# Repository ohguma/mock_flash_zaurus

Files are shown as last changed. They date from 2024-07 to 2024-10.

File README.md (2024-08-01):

# フラッシュザウルスもどき

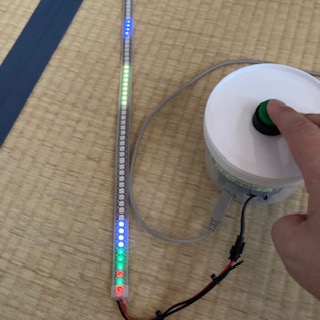
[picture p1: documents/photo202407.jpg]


- Arduino UnoとLEDテープ、パッシブブザーを用いた、フラッシュザウルス風ゲーム。
- 「フラッシュザウルス」については「[東京フレンドパークのアトラクション一覧](https://ja.wikipedia.org/wiki/%E6%9D%B1%E4%BA%AC%E3%83%95%E3%83%AC%E3%83%B3%E3%83%89%E3%83%91%E3%83%BC%E3%82%AF%E3%81%AE%E3%82%A2%E3%83%88%E3%83%A9%E3%82%AF%E3%82%B7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)」を参考に。

## ゲーム概要

以下は、本物のフラッシュザウルスのルールでなく、本スケッチでのルール。
+ ボタンを押すとゲーム開始。
+ 1ゲーム10ラウンド制。
+ arduino本体から離れた位置からLEDドットが近づいてくるので黄色LED上でボタンを押す。
+ 黄色LED上でボタンを押すことができればそのラウンドは成功。黄色LEDを外れると失敗。
+ arduino寄りの10LEDでポイントを表示する。成功は緑、失敗は赤。
+ ラウンド開始後、LEDドットはランダムウエイト後にランダム位置からランダム速度で近づく。
+ 初回の失敗か続けて失敗すると、落下速度の基準を落とす。
+ 黄色LEDはラウンドが進むと短くなる。また配置はランダムにずれる。
+ ボタンを押しながらarduino本体の電源を入れると輝度調整モードに入る。希望輝度でボタンを離す。

## 参考

- https://github.com/adafruit/Adafruit_NeoPixel
  - ライブラリマネージャからインストールしておく。
- https://github.com/lalaso2000/Music/
  - 本ソースに含む。曲データは適宜差し替えた。

## 利用パーツ

リンク先は作例で使用したもの。

+ Arduino UNO Rev.3 で動作確認
  - due は IO電圧が3.3Vだが、WS2812B の操作は可能、ただし、tone()が利用できないため、本スケッチはそのまま利用できない。
    - due 用 tone() の例：https://forum.arduino.cc/t/arduino-due-and-tone/133302/2
  - その他の arduino でも基本的には動作すると思われる。
+ Arduino と LEDテープ・スイッチ・ブザー接続用のユニバーサル基板
  - [スイッチ・サイエンス：Arduino用バニラシールド基板](https://www.switch-science.com/products/991)
    - 別途ピンヘッダ、もしくはピンソケットが必要。
    - （説明）[スイッチ・サイエンス：バニラシールド](https://trac.switch-science.com/wiki/VanillaShield)
  - arduinoのピンソケットはシールド基板の逆接続防止に一部間隔がずれているので、一般的なユニバーサル基板を使う場合はピンヘッダを曲げてズレに対応させる（おすすめはしない）。
+ LEDテープ 144個を想定。amazonで2,000円程度。
  - arduinoのAdafruit_NeoPixelライブラリで利用できるもの。以下で動作確認した。
  - [amazon：ALITOVE WS2812B LEDテープ1m 144連 NeoPixel RGB TAPE LED 5050 SMD LEDテープライトピクセル 防水 黒いベース 5V DC](https://www.amazon.co.jp/dp/B01MYT6JH9/)
    - 2017年10月購入
  - [amazon：BTF-LIGHTING WS2812B LEDテープライト 5050 SMD RGBIC 合金ワイヤー 1m 144LEDs](https://www.amazon.co.jp/dp/B088JTMSYY/)
    - 2024年7月購入
  - WS2812B の詳細はこちらから
    - [秋月電子：マイコン内蔵RGBLED WS2812B](https://akizukidenshi.com/catalog/g/g107915/)
+ パッシブブザー
  - arduinoのtone()で利用できるもの。
  - 電源に接続するだけで音が出るものはアクティブブザーで、tone()で利用できない。
  - [amazon：KKHMF 20個パッシブブザー 電磁 ユニバーサル インピーダンス 16R 12*8.5mm ピッチ 6.5mm](https://www.amazon.co.jp/gp/product/B08LB2GYD1/)
+ 押ボタンスイッチ
  - 押している間だけONになるモーメンタリなものを使う。
  - [モノタロウ：押しボタンスイッチ AR22シリーズ 突形(Φ24) 非照光式 取付穴径22.3/25.5mm モメンタリ 1a](https://www.monotaro.com/p/3492/4644/)
    - 取付穴寸法：直径22mm。ストロークが長いと不評だった。
  - [千石通商：三和電子　OBSF-24](https://www.sengoku.co.jp/mod/sgk_cart/detail.php?code=55AU-8ALR)
    - 取付穴寸法：直径24mm。
+ ケース
  - ダイソーの食品用容器
  - ブザーは側面に穴を開け、UVレジンで固定した。

## 注意
+ LEDをあまり明るくすると電源がもたないかも。
  -  [秋月電子：マイコン内蔵RGBLED WS2812B](https://akizukidenshi.com/catalog/g/g107915/)の[データシート](https://akizukidenshi.com/goodsaffix/WS2812B_20200225.pdff)だと動作電流が「12mA」とあり、144個全てが12mA使うと「1.728A」に達する。

## 基盤情報

### 回路図

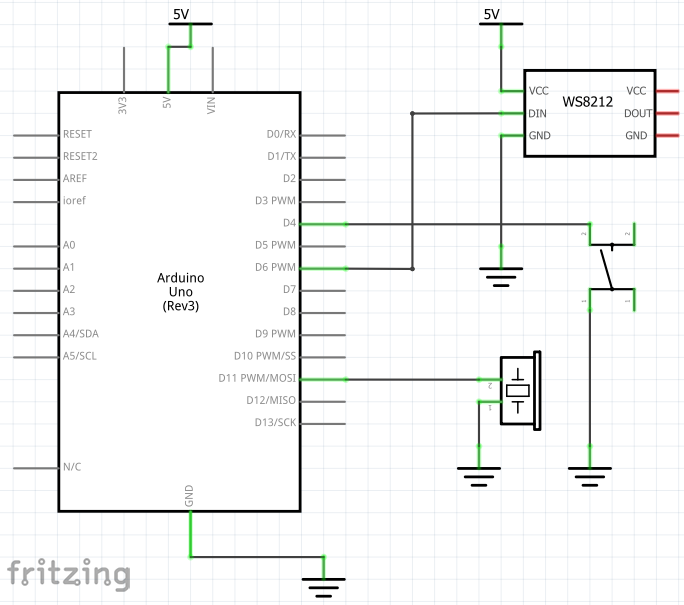
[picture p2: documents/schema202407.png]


### ブレッドボード配線例

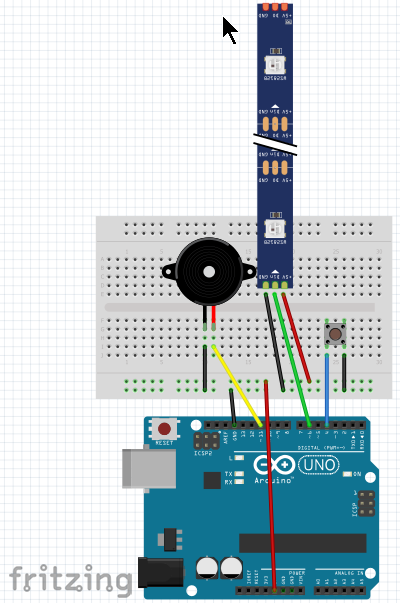
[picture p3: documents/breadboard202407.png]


### シールド基板配線例

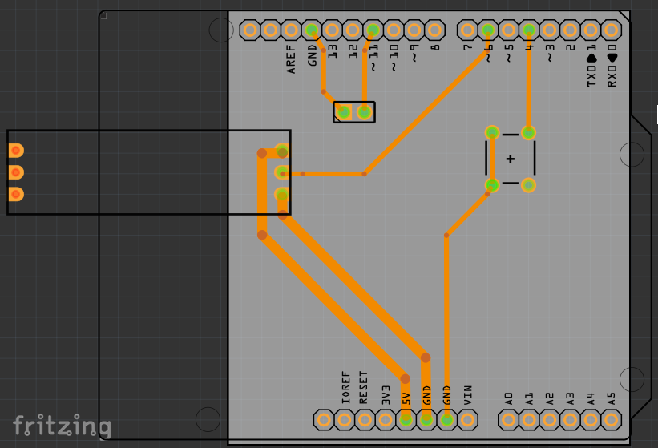
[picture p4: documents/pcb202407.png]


- ケースに入れる場合は適宜コネクタ等利用する。

## CADデータ

- 長さ1mで12mm幅のLEDテープを外径21mm、内径18mm、長さ1mのアクリルパイプにLEDテープを入れてみた。
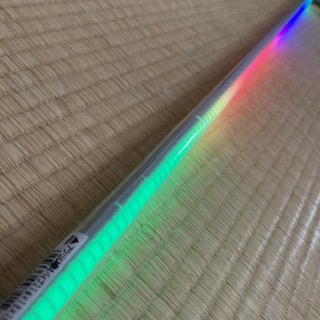
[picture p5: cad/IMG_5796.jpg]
  -  全体。
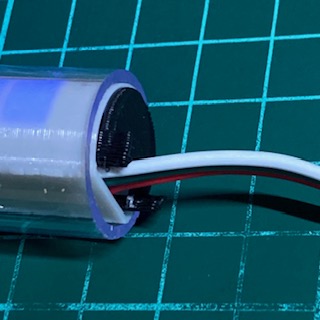
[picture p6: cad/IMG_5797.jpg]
  -  アクリルパイプの端。コードのハンダ部が折れやすいので要注意。
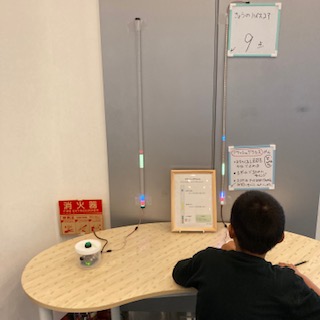
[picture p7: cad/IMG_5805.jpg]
  -   左はアクリルパイプ、右は購入時の防水用カバー。
- 3Dプリンタで作成したパーツは主に３つ
  - 光拡散カバー。長さが2種類。
    - [fz_cov11.stl](./cad/fz_cov11.stl) 長さ：75.6mm 13個
    - [fz_cov4.stl](./cad/fz_cov4.stl) 長さ：27.3mm 1個
    - 白PLA使用。光が透けるものを使う。
      - 使用フィラメント：[eSUN PLA Plus 白](https://www.amazon.co.jp/gp/product/B085TDK2KZ)
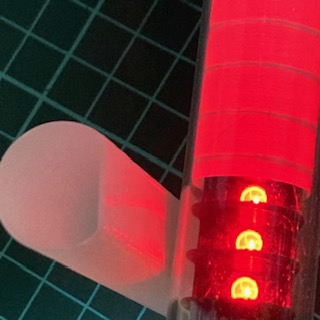
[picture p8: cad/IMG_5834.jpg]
      -  発光部の近影。カバーは筒を立てる向きに印刷。
  - 光拡散カバー内の仕切り。長さが2種類。LEDは6.9mmごとに設置されているので、仕切りも合わせる。
    - [fz_div13.stl](./cad/fz_div13.stl)  長さ：88.4mm 11個
    - [fz_div4.stl](./cad/fz_div4.stl) 長さ：27.3mm 1個
    - 黒PLA使用。光が透けないものを使う。透けると色が混ざる。
      - 使用フィラメント：[ELEGOO PLAフィラメント黒](https://www.amazon.co.jp/dp/B0BM4DQHQH)
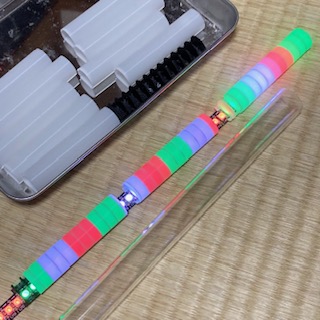
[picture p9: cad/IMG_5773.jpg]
      -  仕切り3種の比較。右上：白PLA、中：白PLAを黒マッキー塗装、左下：黒PLA。
  - アクリルパイプ両端のふた。コードの有無で2種類。 
    - [fz_futa.stl](./cad/fz_futa.stl) 
    - [fz_futa2.stl](./cad/fz_futa2.stl)
- 各STLファイルは、使用している3Dプリンタ（ANYCUBIC MEGA-S）で出力したものが、基本無加工でアクリルパイプに収まるよう大きさを調整している。
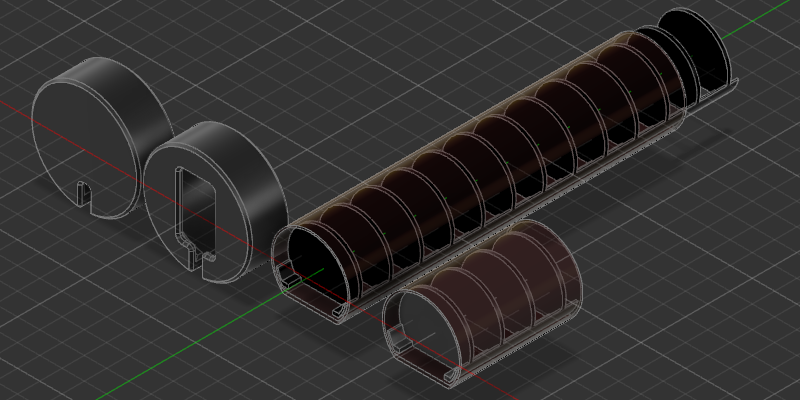
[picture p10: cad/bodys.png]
  - 
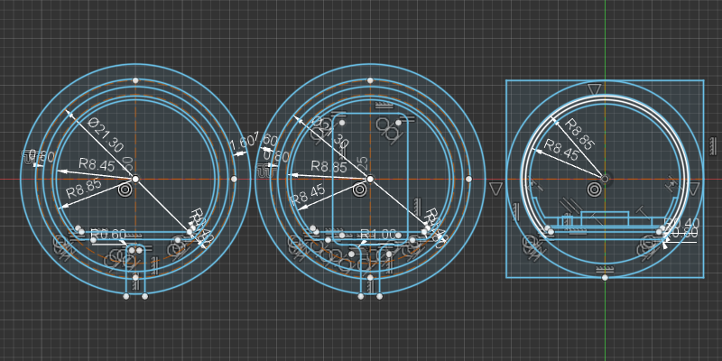
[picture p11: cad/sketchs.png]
  - 

----

- 2024-08-01 ohguma アクリルパイプへの仕込み、CADデータ追加、ソース更新
- 2024-07-18 ohguma 本ドキュメント追記、画像更新
- 2024-07-07 ohguma 低得点時の補正、ハイスコア表示、等対応
- 2024-07-06 ohguma 初版

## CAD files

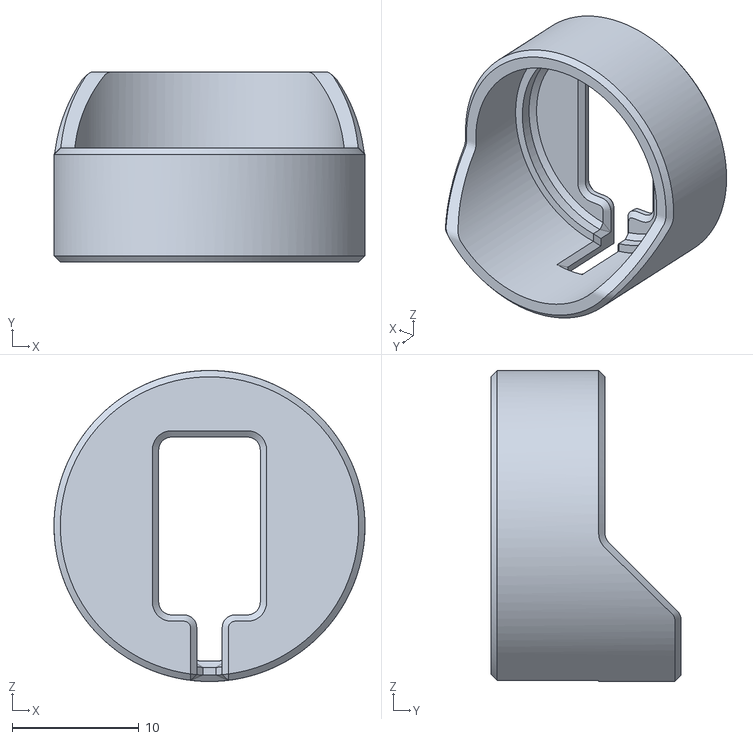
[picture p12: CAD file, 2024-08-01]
cad/fz_futa.stl
24.5 x 15.0 x 24.5

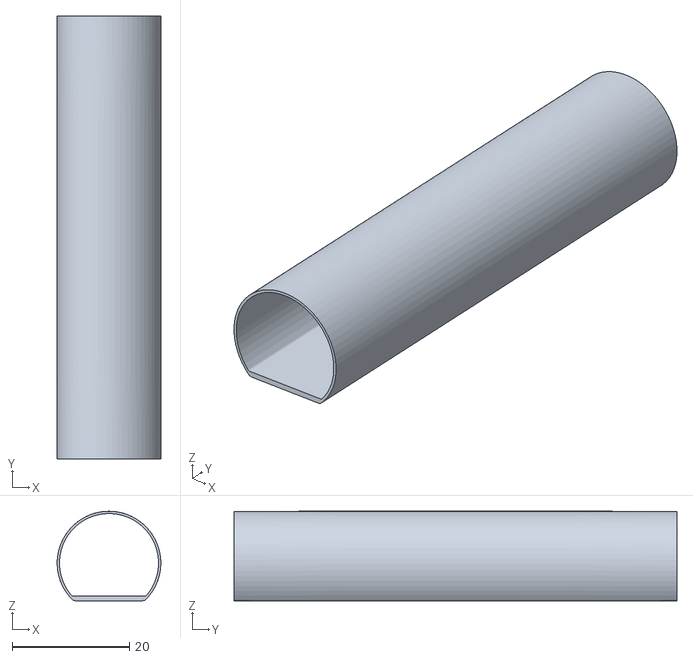
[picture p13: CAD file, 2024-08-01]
cad/fz_cov11.stl
17.7 x 75.6 x 15.3

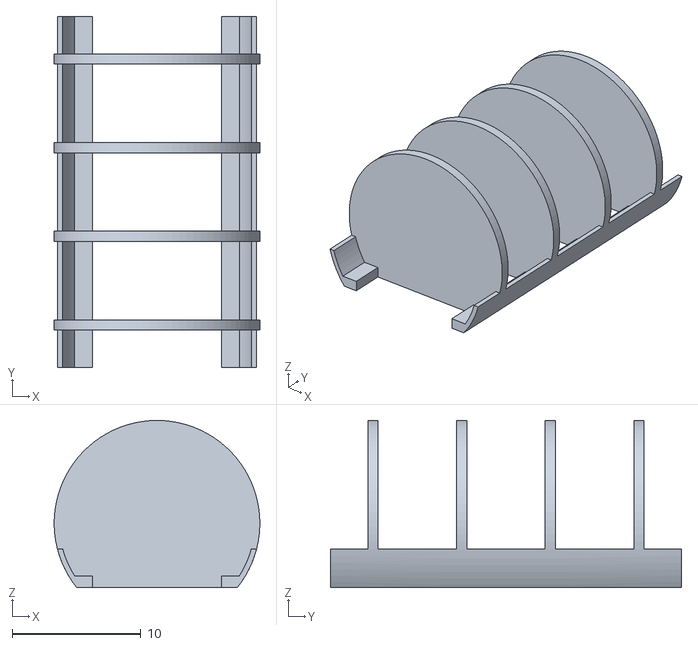
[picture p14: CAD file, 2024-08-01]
cad/fz_div4.stl
16.0 x 27.3 x 13.0

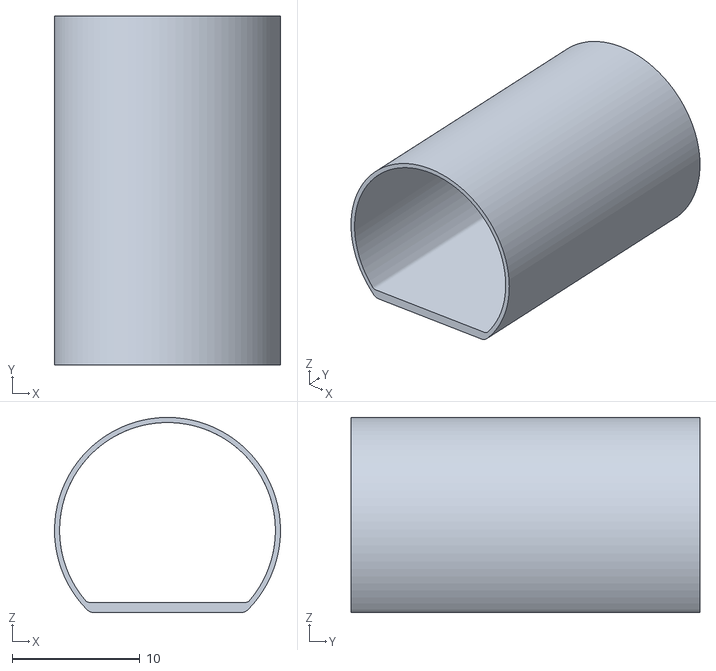
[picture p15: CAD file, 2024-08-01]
cad/fz_cov4.stl
17.7 x 27.3 x 15.3

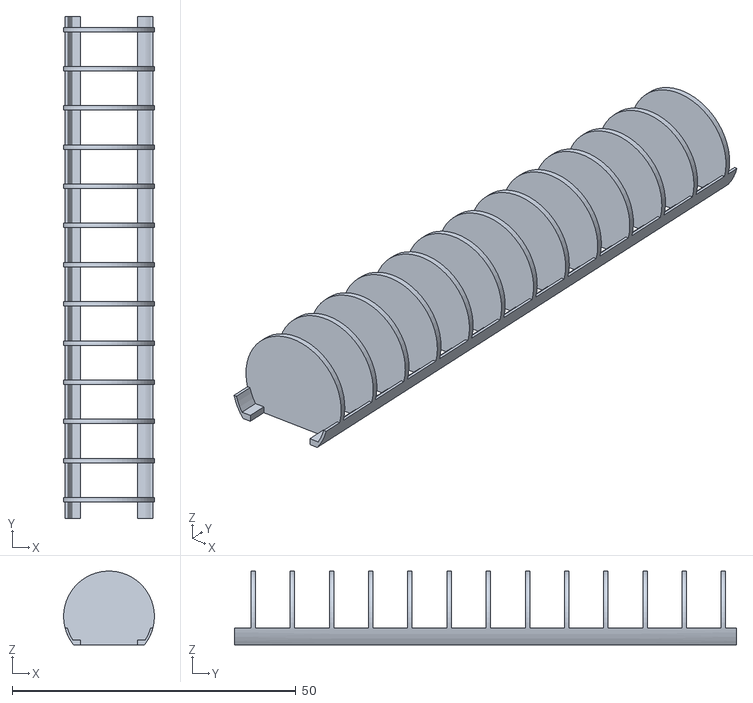
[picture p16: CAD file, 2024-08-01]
cad/fz_div13.stl
16.0 x 88.4 x 13.0

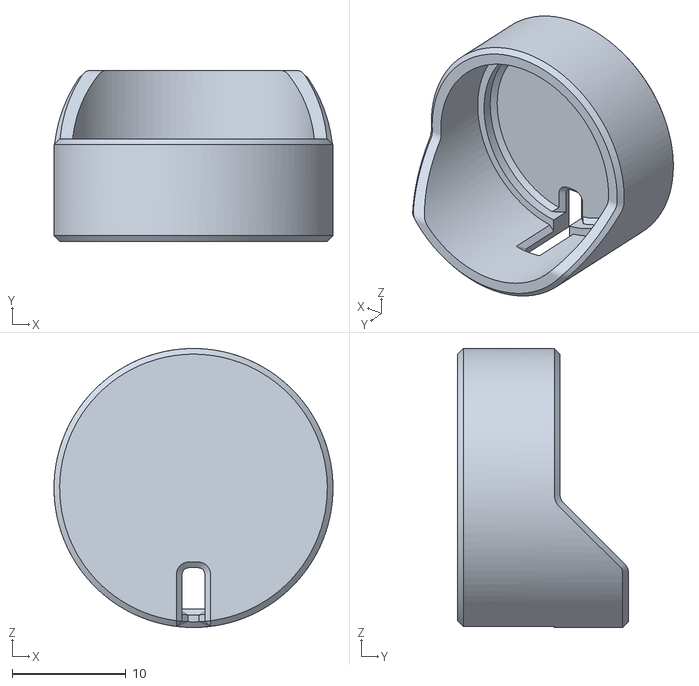
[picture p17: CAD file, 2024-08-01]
cad/fz_futa2.stl
24.5 x 15.0 x 24.5

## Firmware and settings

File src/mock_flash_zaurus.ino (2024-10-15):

/*
フラッシュザウルスもどき
https://github.com/ohguma/mock_flash_zaurus
2024-07-22 ohguma

■必要パーツ
・Arduino Uno等
・押ボタンスイッチ
・LEDテープ144連
・パッシブブザー
・ケース、電源等

LEDテープはAdafruit_NeoPixelで利用できるもの。144個を想定
ALITOVE WS2812B LEDテープ1m 144連 NeoPixel RGB TAPE LED 5050 SMD LEDテープライトピクセル 防水 黒いベース 5V DC
https://www.amazon.co.jp/dp/B01MYT6JH9/

パッシブブザー
tone()関数で制御できるもの。電源につなぐだけでは鳴らない。
KKHMF 20個パッシブブザー 電磁 ユニバーサル インピーダンス 16R 12*8.5mm ピッチ 6.5mm
https://www.amazon.co.jp/gp/product/B08LB2GYD1/

押ボタンスイッチは丈夫なものを使う
押しボタンスイッチ AR22シリーズ 突形(Φ24) 非照光式 取付穴径22.3/25.5mm モメンタリ 1a
https://www.monotaro.com/p/3492/4644/

演奏には下記を利用する。
https://github.com/lalaso2000/Music/

*/

#include "led.h"
#include "effect.h"
#include "music.h"

#define PIN_SW 4                       // スタート兼回答スイッチピン
#define NUM_RANGE_DEFAULT 15           // ゲーム開始時の正解ゾーンLED数
int pos_ok_begin = 20;                 // 正解ゾーン開始位置。実際はランダム配置
int num_ok_range = NUM_RANGE_DEFAULT;  // 正解ゾーン個数。だんだん減る。
int score = -1;                        // 得点 0～10。-1はまだ誰も挑戦していないとき
int hi_score = -1;                     // ハイスコア
unsigned long delay_fall = 1;          // ドット落下時待機時間
unsigned long delay_move = 25;         // 押した後のドット移動時待機時間
int fall_hosei = 0;                    // 落下速度補正。低得点時の高速落下回避用

#define NUM_ATARI 10      // 回答数
int atari[NUM_ATARI];     // 回答状態 0:未回答 1:OK 2:NG
int hi_atari[NUM_ATARI];  // ハイスコア回答状態 0:未回答 1:OK 2:NG


void setup() {
  Serial.begin(9600);
  pinMode(PIN_SW, INPUT_PULLUP);
  int light = 3;  // LED明るさ基準値(5段階、1:暗～5:明)
  pixels.begin();
  pixels.setBrightness(light * 4);  // 輝度設定 x/255 (max = 255)
  delay(1000);
  set_color();
  //ハイスコアクリア
  for (int i = 0; i < NUM_ATARI; i++) {
    hi_atari[i] = 0;  //0:未回答,1:OK,2:NG
  }
  //スイッチONで明るさ調整
  unsigned long tm = millis();
  while (digitalRead(PIN_SW) == LOW) {
    pixels.clear();
    light = ((millis() - tm) / 1000 + 2) % 5 + 1;  //1秒ごとに明るさ基準値変更（3始まり）
    pixels.setBrightness(light * 4);               // 輝度調整 x/255 (max = 255)
    pixels.setPixelColor(5, pixels.Color(255, 0, 0));
    for (int i = 0; i < light; i++) {
      pixels.setPixelColor(i, pixels.Color(255, 255, 255));
    }
    pixels.show();
    delay(50);
  }
  pixels.clear();
  pixels.show();
}

//帯位置決定、表示
void disp_obi() {
  //帯オン
  pos_ok_begin = 20 + random(8) * 2;
  for (int i = pos_ok_begin; i < pos_ok_begin + num_ok_range; i++) {
    pixels.setPixelColor(i, color_obi);
  }
}

// 結果表示
void disp_atari(int start = 0) {
  for (int i = 0; i < NUM_ATARI; i++) {
    if (atari[i] == 1) {
      // 1:OK
      pixels.setPixelColor(i + start, color_ok);
    } else if (atari[i] == 2) {
      // 2:NG
      pixels.setPixelColor(i + start, color_ng);
    } else {
      // 0:未回答
      pixels.setPixelColor(i + start, color_none);
    }
  }
}

void loop() {
  //theaterChaseRainbow(1000);
  int h, i, j;
  // スタート待機
  unsigned long tm = millis();
  unsigned long tm2 = millis();
  long t = 250;   //周期[ms]
  long p = 110;   //0.5t 時の頂点  x=0.5t時に -x*(x-t) / k = p
  long t2 = 333;  //ハイスコア用周期[ms]
  long p2 = 110;  //ハイスコア用0.5t 時の頂点  x=0.5t時に -x*(x-t) / k = p
  //隣接スコアが頂点同士でつながって見えないようにするための+1
  if (score == -1) {
    p = (random(10) + 1) * (NUM_ATARI + 1);
  } else {
    p = (score + 1) * (NUM_ATARI + 1);
    p2 = (hi_score + 1) * (NUM_ATARI + 1);
  }
  t = p + 250;
  t2 = p2 + 333;
  long k = t * t / 4 / p;
  long k2 = t2 * t2 / 4 / p2;
  while (digitalRead(PIN_SW) == HIGH) {
    pixels.clear();
    long x = millis() - tm;
    long x2 = millis() - tm2;
    long y = -x * (x - t) / k;       //2次曲線。放物線
    long y2 = -x2 * (x2 - t2) / k2;  //2次曲線。放物線
    if (y < 0) {
      if (score == -1) {
        p = (random(10) + 1) * 10;
        t = p + 250;
        k = t * t / 4 / p;
      }
      tm = millis();
      x = 0;
      y = 0;
    }
    if (y2 < 0) {
      tm2 = millis();
      x2 = 0;
      y2 = 0;
    }
    if (score != -1 && hi_score > 1 && score != hi_score) {
      for (int i = 0; i < NUM_ATARI; i++) {
        if (hi_atari[i] == 1) {
          // 1:OK
          pixels.setPixelColor(i + y2, color_hi_ok);
        } else {
          // 2:NG
          pixels.setPixelColor(i + y2, color_hi_ng);
        }
      }
    }
    disp_atari(y);
    pixels.show();
  }
  // 開始
  score = 0;
  fall_hosei = 0;
  num_ok_range = NUM_RANGE_DEFAULT;
  for (int i = 0; i < NUM_ATARI; i++) {
    atari[i] = 0;  //0:未回答,1:OK,2:NG
  }
  pixels.clear();
  disp_obi();  //初回は帯表示して、開始音
  pixels.show();
  sound_start();
  for (h = 0; h < NUM_ATARI; h++) {
    if (h > 0) {
      pixels.clear();
      disp_obi();
    }
    disp_atari();
    pixels.show();
    if (h > 0) {
      //押されっぱなしの場合、待機
      while (digitalRead(PIN_SW) == LOW) {
        delay(10);
      }
      //ランダム待機
      delay(random(3000) + 500);
    }
    //落下速度決定
    delay_fall = pow((h == 0 ? 4 : random(4)) + fall_hosei + 1, 2);
    //落下開始位置決定
    int pos_start = LED_NUM_PIXELS - 1 - random(8) * 3;
    //流星開始
    for (i = pos_start; i >= NUM_ATARI; i--) {
      if (i < pos_start) {
        //ドット消し
        if (i + 1 >= pos_ok_begin && i + 1 < pos_ok_begin + num_ok_range) {
          pixels.setPixelColor(i + 1, color_obi);
        } else {
          pixels.setPixelColor(i + 1, 0);
        }
      }
      //新ドット
      pixels.setPixelColor(i, color_fall);
      pixels.show();
      if (digitalRead(PIN_SW) == LOW) {
        break;
      }
      delay(delay_fall);
    }
    // あたり判定
    if (i == NUM_ATARI - 1) {
      // 未回答時のドット位置調整
      i = NUM_ATARI;
    }
    // ドット色変更
    unsigned long c;
    if (i >= pos_ok_begin && i < pos_ok_begin + num_ok_range) {
      //当たり
      score++;
      atari[h] = 1;  //OK
      c = color_ok;
      pixels.setPixelColor(i, c);
      pixels.show();
      sound_ok();
    } else {
      //ハズレ
      atari[h] = 2;  //NG
      c = color_ng;
      pixels.setPixelColor(i, c);
      pixels.show();
      sound_ng();
    }
    //ドット移動
    int k;
    //ドットより奥に帯が残っていれば削除
    if (i < pos_ok_begin + num_ok_range) {
      if (i >= pos_ok_begin) {
        k = i + 1;
      } else {
        k = pos_ok_begin;
      }
      for (j = pos_ok_begin + num_ok_range - 1; j >= k; j--) {
        pixels.setPixelColor(j, 0);
        pixels.show();
        delay(delay_move);
      }
    }
    for (j = i; j > h; j--) {
      //ドット消し
      if (j < NUM_ATARI) {
        pixels.setPixelColor(j, color_none);
      } else {
        pixels.setPixelColor(j, 0);
      }
      //新ドット
      pixels.setPixelColor(j - 1, c);
      pixels.show();
      delay(delay_move);
    }
    num_ok_range--;
    if (score == 0 || (h > 0 && atari[h] == 2 && atari[h - 1] == 2)) {
      //低得点時の高速回落下避設定
      fall_hosei++;
    }
    delay(2000);
  }
  //ハイスコア
  if (score > 0 && score >= hi_score) {
    hi_score = score;
    for (int i = 0; i < NUM_ATARI; i++) {
      hi_atari[i] = atari[i];  //0:未回答,1:OK,2:NG
    }
  }
  //終了音
  if (score == NUM_ATARI) {
    playMusic(PIN_TONE, marioClear, 150);
    //theaterChaseRainbow(3000);
    effect_firework(5);
    pixels.clear();
    disp_atari();
    pixels.show();
    delay(500);
  } else {
    playMusic(PIN_TONE, marioOver, 150);
  }
}

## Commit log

2024-07-06 ラウンド終了後に帯色が残る不具合修正など
2024-07-07 低得点時の補正、ハイスコア表示、等対応
2024-07-19 ドキュメント追記、画像更新
2024-08-01 ソースの整理
2024-08-01 アクリルパイプ用のSTL追加
    [fz_cov11.stl, fz_cov4.stl, fz_div13.stl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]
2024-08-01 アクリルパイプを使った工作例の追加
2024-10-15 初回失敗で萎えないよう、初回速度低下対応。
